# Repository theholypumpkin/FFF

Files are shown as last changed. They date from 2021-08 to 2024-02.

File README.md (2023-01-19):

# NOTE: README ist nicht up to date, Ich werde es irgendwann mal anpassen :D
# Digitales Fridays For Future Demoschild
Dieser Python Skript stellt diverse Bilder sowie live gemessende CO2, Temperatur, Luftfeuchtigkeit sowie Optional Stromverbrauch auf zwei 32x32 LED Matrizen dar.
Der Skript wird auf einem RaspberryPi Pico der Adafruit's Circuit Python 6.3 als Python Interpreter nutzt.

## Anleitung zum selbermachen:
### __Wichtige__ Vorrausetztungen und Vorwissen
- Du musst wissen wie man lötet, oder jemanden kennen der Löten kann
- Erfahrung in der Elektronik (keine Sorge wir arbeiten mit Sehr geringen Spannungen (5V) und Strömen (3A))
- Grundlegende Verständnisse in Programmierung (Sprache Python)

### Material
Das notwendige Material kannst du online bestellen, oder im Laden kaufen, leider gibt es in Deutschland nur wenige Verkäfter mit vernünftigen Preisen. Ich versuche immer einen Weblink zuim kaufen bei mindestens einem Deutschen Händer und einen Händler in der EU oder Großbritannien (GB) an.
Lese bevor du etwas käuftst am besten die gesamte Anleitung einmal durch.

__Wichtig für bestellungen auserhalb des Europäischen Binnenmarkt ist Zoll zu zahlen, der wird oft im Preis nicht angegeben__

*Dem Klima zu liebe verucht bei so weingen Händlern wie möglich zu kaufen dann mussen weniger Parkete verschickt werden, die meisten Produkte findest du bei Reichelt und Pimoroni (GB)*

| Produkt | Händler 1 (DE) | Handler 2 (DE) | Händler 3 |
| --- | --- | --- | --- |
| 1x Raspberry Pi Pico | [Reichelt Elektronik, 3,95 € Online](https://www.reichelt.de/raspberry-pi-pico-rp2040-cortex-m0-microusb-rasp-pi-pico-p295706.html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) | [Conrad Electronic Online, 7,99 €](https://www.conrad.de/de/p/raspberry-pi-mikrocontroller-rp-pico-2348726.html) |  [(GB) Pimoroni, 3,54 €  Online](https://shop.pimoroni.com/products/raspberry-pi-pico) |
| 2x RGB LED Matrizen 32x32 6mm Raster | [Berry Blase; Bereits 32x64 6mm Raster; NUR einmal kaufen 66,90 € Online](https://www.berrybase.de/sensoren-module/led/andere-led-module/64x32-rgb-led-matrix-6mm-raster) | | [(GB) Pimoroni 32x32 6mm Raster 17,70 € Online](https://shop.pimoroni.com/products/rgb-led-matrix-panel) |
| 1x Solar-Charger 1 Ampere (Optional) | [Reichelt Elektronik 9,99 ](https://www.reichelt.de/entwicklerboards-solar-ladegeraet-fuer-6-bis-24-v-panels-debo-pwr-solar2-p266038.html) | [Eckstein Komponente 9,69 € Online](https://eckstein-shop.de/WaveshareSolarPowerManagementModule2Cfor6V-24VSolarPanelEN)
| 2x Solarzellen (Optional) | [Reichelt Elektronik 12,90 € Online](https://www.reichelt.de/entwicklerboards-solarpanel-5-w-debo-solar-5w-p266039.html) | [Amazon 14,99 € Online (Empfehlung)](https://www.amazon.de/gp/product/B08GQ611T2?psc=1) | |
| Solar-Charger 3 Ampere mit __eingebauter Batterie__ (Optional) | | | [(China) Waveshare 25,99$ Online (Empfehlung)](https://www.waveshare.com/product/accessories/power-heat-sinks/solar-power/solar-power-manager-b.htm)|
| 1x Li-Po Batterie (für etwa 45min bis 1h Akkulaufzeit. LED Matrizen haben einen hohen Stromverbrauch) | | | [(GB) Pimoroni 13,27 € Online](https://shop.pimoroni.com/products/high-capacity-lithium-ion-battery-pack) |
| 1x CO2 Sensor CCS881| [Reichelt Elektronik 17,10 € Online](https://www.reichelt.de/entwicklerboards-sensor-fuer-luftqualitaet-ccs811-debo-sens-ccs811-p253655.html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) | | [(GB) Pimoroni 18,29 € Online](https://shop.pimoroni.com/products/adafruit-ccs811-air-quality-sensor-breakout-voc-and-eco2) |
| 1x Temperatursensor DHT22 | [Reichelt Elektronik 6,80 € Online](https://www.reichelt.de/entwicklerboards-temperatur-feuchtigkeitssensor-dht22-debo-dht-22-p224218.html) | [Conrad Electronics Online, 8,49 €](https://www.conrad.de/de/p/joy-it-sen-dht22-temperatur-sensor-1-st-passend-fuer-entwicklungskits-arduino-asus-asus-tinker-board-banana-pi-b-2159178.html) | [(GB) Pimoroni 11,21 € Online](https://shop.pimoroni.com/products/cm2302-dht22-temperature-humidity-sensor-module) |
| Stromsensor INA219 (Optional, wenn du Stromverbrauch messen willst)) | [Reichelt Elektronik 4,15 € Online](https://www.reichelt.de/entwicklerboards-stromsensor-mit-breakoutboard-ina219-debo-sens-power-p266047.html) | | [(GB) Pimoroni 8,85 € Online](https://shop.pimoroni.com/products/ina219-high-side-dc-current-sensor-breakout-26v-3-2a-max-stemma-qt) |
| Diverse Header zum anlöten |[Reichelt 2x 1,35 € Online](https://www.reichelt.de/buchsenleiste-20-polig-vergoldet-2-54-bkl-10120828-p235676.html) & [1x 0,21 € Online](https://www.reichelt.de/40pol-stiftleiste-gerade-rm-2-54-sl-1x40g-2-54-p19506.html) & [1x 2,25 € Online](https://www.reichelt.de/stiftleisten-2-54-mm-1x36-gewinkelt-vergoldet-fis-sl3-25-36g-p292528.html) | | [(GB) Pimoroni (Set mit allem Möglichen Sachen) 6,19 € Online](https://shop.pimoroni.com/products/maker-essentials-various-headers)|
| Divere Kabel zum verbinden | [Reichelt Elektronik 4,80 € Online](https://www.reichelt.de/entwicklerboards-steckbrueckenkabel-25cm-20-kabel-einzeln-debo-kabelset4-p238964.html) | | |
| 1x Hohlstecker zum anschrauben/löten | [Reichelt Elektronik 0,26 € Online](https://www.reichelt.de/hohlstecker-knickschutz-aussen-5-5-mm-innen-2-5-mm-hs-25-14-p8648.html) | [Conrad Electronics, 3,99 €  Online (Einfacher)](https://www.conrad.de/de/p/tru-components-dc-13m-niedervolt-steckverbinder-stecker-gerade-5-5-mm-2-5-mm-1-st-1572162.html) | |
| 1x LED matrix Feather Wing (Optional aber macht das leben einfacher) | [Berry Blase 7,75 € Online](https://www.berrybase.de/dev.-boards/adafruit-feather/featherwing/adafruit-rgb-matrix-featherwing-kit-f-252-r-feather-m0-und-m4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) | [Amazon 14,06 € Online](https://www.amazon.de/Adafruit-RGB-Matrix-Featherwing-Kit/dp/B07GYYB795) | [(GB) Pimoroni 7,08 € Online](https://shop.pimoroni.com/products/adafruit-rgb-matrix-featherwing-kit-for-m0-and-m4-feathers)
| Stemma QT Kabel (optinal wenn du weniger löten willst) Nur möglich wenn du auch den CO2 Sensor und den Stromsensoren bei Pimoroni/Adafruit/Sparkfun kauft| | | [(GB) Pimoroni 1,47 € Online](https://shop.pimoroni.com/products/jst-sh-cable-qwiic-stemma-qt-compatible?variant=31910609846355) & 2x dieses Kalbel (nur wenn du Stromsensor hast)[(GB) Pimoroni 1,47 € Online](https://shop.pimoroni.com/products/jst-sh-cable-qwiic-stemma-qt-compatible?variant=31910609813587)|
| 2x Alte USB Handy-Ladekabel, eins davon wird zerschnitten| | | |
| Wekzeuge wie Schraubenzieher Schraubenschüssen, Sägen, Akkubohrer, Sandpapier, etc. | | | |
| Steckplatine (optional, macht aber das löten um einiges einfacher)| | | |
| Eine Holzkonstruktion, und  dazu passende Schrauben. Hier lass ich dir freie Auswahl wie du diese Gestalten willst. | | | |

So jetzt wo alles hast können wir anfangen.

## Schritt 1 Löten
Wir fangen mit dem Löten der einzelen Komponenten an:
#### 1.
* Wenn deine Stromsensoren (INA219) und CO2 sensor (CCS881) von Pimoroni,Adafruit oder Sparkfun und die Optionale Stemma QT/Qwiic Kabel gekauft hast dann kannst du dir etwas löten ersparen, und einfach nur 2 Sensoren in eine Reihe Stecken, Diese Sensoren haben auf den beiden kuzen Seite einen Steckverbinder wo man ein Solches Kabel einstecken kann. Wenn du von Anderen Herstellen gekauft hast, dann musst du die (meistens Beigelegte) Stiftleiste anlöten. [Hier gibt es eine Anleitung mit Bildern, wie du das bei dem CO2 Sensor macht, das selbe gilt auch für den Stromsensor](https://learn.adafruit.com/adafruit-ccs811-air-quality-sensor/assembly).
#### 2.
* Je nachdem wo du deinen Temperatur und Luftfeuchtigkeitssensor gekauft hast, musst du löten oder auch nicht. bei dem von Pimoroni musst du nicht löten, braucht keine Platine zum anlöten oder Wiederstände, der Kommt komplett vorbereitet, du muss dann nur die Kabel anschließen.[Wenn du einen der anderen hast, dann kannst du hier naschauen wie du ihn anschließt](https://learn.adafruit.com/dht/connecting-to-a-dhtxx-sensor). Achte auf den Wiederstand von _20-50 Kilo Ohm_.
Damit sind alle Snesoren vorbereitet.
#### 3.
* Nun müssen wir die Buchsenleistenleisten an den Raspberry Pi Pico anlöten. Eine Buchenleiste sieht wie im Bild hier aus: Bild 1 Buchsenleiste
* Der Raspbbery Pi Pico hat 40 Sogenannte Pins oben. Davon habe 28 spezielle Funktionen. Interessiert uns aber alles nicht. Um uns das leben einfacher zu machen, schauen wir uns das Pinout Diagram an was der Hersteller bereit stellt. Bild 2 Raspberry Pi Pico Pinout Pinout Diagram. Hier ist sehr viel zu sehen, aber vieles ist für dich egal, wenn du den Quellcode nicht verändern willst.
* Wir Orientiern nun unseren Raspberry Pi Pico genauso wie im Bild, das Logo mit der Himbeere kommt nach unten und die USB Buchse kommt nach oben.
* Nun suchen wir aus unsern Set an Buchenleisten So viele raus, das wir insgesamt 12 Buchen haben. Wenn du das Set von Pimoroni gekauft hast, dann musst du die Kurzen Enden der buchen mit Sandpapier etwas abreiben, damit sie nebeneinander passen. Wenn du von Reichelt gekauft hast, kannst du dir einfach 14 von den 20 Buchen abschneiden. Du braucht 2 mal Leisten der Länge 12 und 2 mal gewinkelte Stiftleisen der Länge 6.
* * Diese Leisten löten wir jetzt auf beide Seiten an, so das sie nach oben Zeigen. Das heißt wir wollen die Leisten und die Himbeere zugleich sehen können. Wir löten sie aber nicht irgendwo an.
* * Vergleiche das Diagram und seine Beschriftungen Die Leisten werden von Pin 7 (GP5) bis Pin 18 (GND) angelötet, die oberen 6 Pins neben der USB-Buche bleiben frei. Um zu wissen wo diese Pins sind, könne wir uns wieder das Pinout Diagram anschauen. Jeder der Pins zwischen Pin 7 und 18 muss angelötet werden.
* * * auf der anderen Seite machen wir das selbe. Wir lassen wieder die Oben 6 Pins frei. Löten die Buchenleiste an alle Pins zwischen Pin 34 (GP38) und Pin 23 (GND) an.
* * * Ihr könnt nochmal Prüfen auf beiden Seiten  des USB Stecker 6 "Löcher"  frei sind und auf Beiden Seiten unten bei der Himbeere jeweils 2 "Löcher" sind.
* *  * Nun kommen wir zu den 6 oben Freigelassen Pins auf beiden Seiten. diese füllen wir mit den Gewinkelten Stiftleisten auf. Also die die um die Ecke gehen. Bild 3 Gewinkelte Buchsenleiste du kannst einfach 6 abscheiden von denen die du gekauft hast.
Damit ist der Raspberry Pi Pico fertig gelötet, lege ihn ersteinmal beiseite, ihn brauchen wir erst einmal nicht.
#### 4.
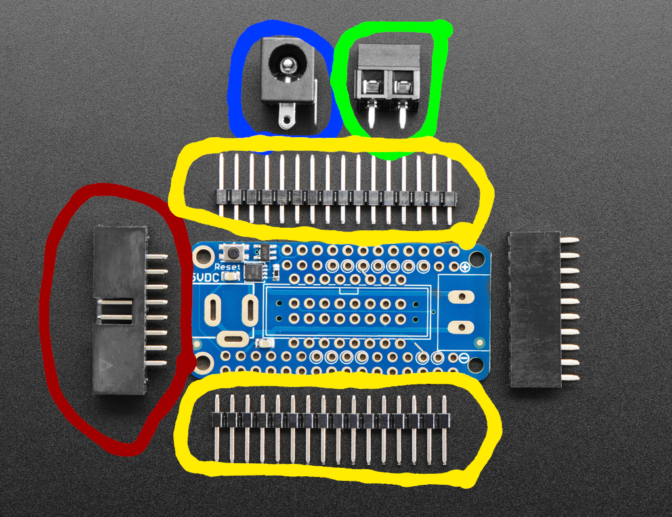
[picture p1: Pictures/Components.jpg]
Bild 1 Featherwing Bild 5 Komponenten
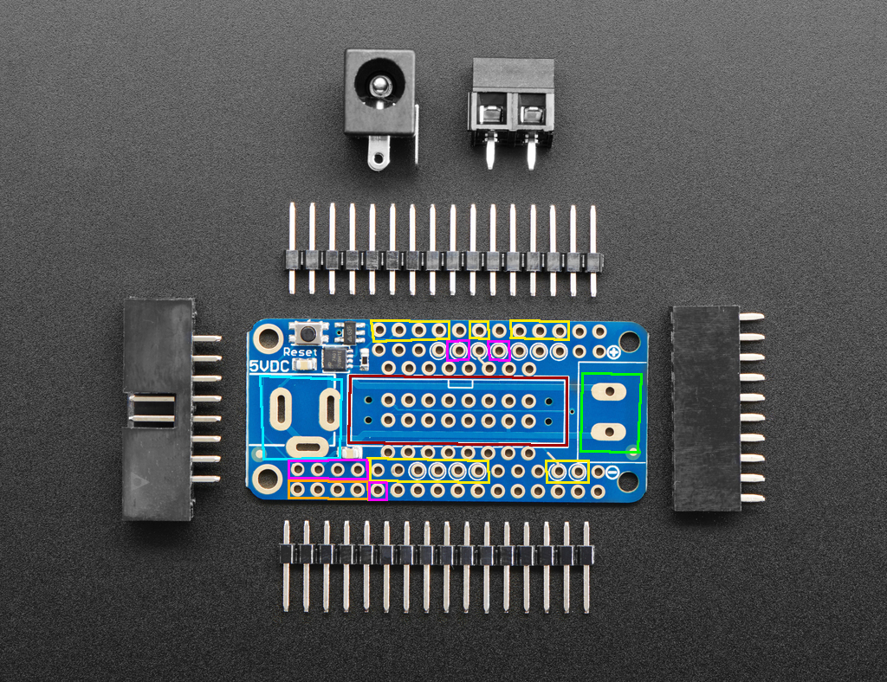
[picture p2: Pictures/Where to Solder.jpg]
Bild 6 Featherwing Bild 2 Wo hin löten
* Nun Kommen wir zum Löten, des "Featherwings", der ist realtiv komplizert zu löten, wenn du Probleme damit hast, dann frage einen Verwanten oder einen Freund. Im Set ist sehr viel Zeug, wir brauchen, da haben den Hohlsteckerbuchse (im Bild 5 Blau), den IDC Buchse auch Schneidklemme genannt (im Bild 5 Rot), eine Schraubklemme (im Bild 5 Grün), und ein paar Stiftleisten (im Bild 5 Gelb).  
* Wir fangen mit der IDC Buchse/Schneidklemme Bild 5 (Rot) an. Die ist ja im Bild 6 (Rot) makiert und hat auf einer Seite eine Kerbe. __Die Kerbe ich ganz wichtig!__ Die IDC Buchse/Schneidklemme gehört auf dem Featherwing in die Mitte (auch Rot markiert). __Achte auf die Kerbe, die auch auf dem Featherwing Markiert ist. Die Kerbe auf der IDC Buchse muss auf der Selben Seite sein, wie die des Featherwing__
* Jetzt kommen wir erst einmal zum Schwersten Teil, die Stiftleisten.
* * an alle im Bild 6 (__GELB__) Markierten Flächen, und auch __nur__ an diesen positionen Brauchen gerade Stiftleisten nach Unten. Wenn du dir nicht sicher bist, was die Geraden Stiftleisten sind, hier ist noch einmal ein Bild Bild 7 Gerade Stiftleiste. Mit Stiftleisten nach unten ist gemeint, dass wenn wir den "Featherwing" genauso wie in Bild 5 vor uns haben, dann können wir die Stifte nicht sehen. __Aufpassen, die Stifte sind versetzt. Einmal sind sie auf der äußerne Reihe und einmal auf der mittleren Reihe__
* * An den Magenta/Lila sind Auch Stifte anzubringen, aber diese mal Müssen sie nach __Oben__ Zeigen! Das heißt wenn wir wollen die Stift sehen, wenn wir den "Featherwing" genauso wie im Bild 6 Betrachten.
* * Nun kommen noch an die Orange makierten Stellen gewinkelte Stifte wie im letzten Unterpunkt von Punkt 3.
* Als nächstes installieren wir die Schraubklemme Bild 5 (Grün) auf der Rechten Seite Bild 6 (Grün). Stelle sicher, das die Schrauböffnung nach Außen zeigt.
* Installiere die Hohlsteckerbuchse Bild 5 (Dunkelblau) an die Stelle in Bild 6 (Hellblau), hier kannst du eigentlich nichts flasch machen es geht nur in ein einzige weise anzulöten.
Nun haben wir alles angelötet fast ferig mit dem allem was Gelötet werden muss aber das Kommt später noch einmal.
## Schritt 2 Vorbereiten und Programmieren den Reaspberry Pi Pico
#### 1.
* Wir gehen in Internet und [laden uns Circuit-Python 6.3.0 herunter](https://circuitpython.org/board/raspberry_pi_pico/). Wen zu deinem Zeitpunkt bereits eine neuere Version verfügbar ist, dann musst du trotzdem die Version 6.3.0 installieren, die "alte" Verion die du brauchts findest du [hier](https://adafruit-circuit-python.s3.amazonaws.com/bin/raspberry_pi_pico/de_DE/adafruit-circuitpython-raspberry_pi_pico-de_DE-6.3.0.uf2 "Direct Download") Nun müssen wir die Datei auf den Rasperry Pi Pico kopieren. Dafür musst du den Knop der auf dem Pico ist gedrückt halten, und dann ihn mit dem Handy-Lade-Kabel an dne Computer anschließen. In deinem Datei-Explorer auf dein Computer Müsste nun eine "USB-Stick" names __`RPI-RP2`__ auftauchen. Nun ziehst du einfach die Datei die du heruntergelanden hast, in diesen Ordner. Der __`RPI-RP2` "USB-Stick" sollte verschwinden__, und kurz darauf ein neuer "USB-Stick" names __`CIRCUITPY`__ auftauchen. Das wars. Lasse den Raspberry Pi Pico eingesteckt in deinem Computer. *Falls du probleme hattest, hier ist noch einmal eine [Anleitung online](https://learn.adafruit.com/getting-started-with-raspberry-pi-pico-circuitpython/circuitpython)*
#### 2.
* Nun gehst du auf dieser Website wo du gerade das ließt, ganz nach oben, und dort ist ein Grüner Knopf, der sagt __Code__ wenn du darauf klickst, dann bekommst du ein kleines Fester. Hier gibt es einen weitern Knopf Names __Download Zip__ diesen klickst du an und der Quellcode für das Demoschild wird Heruntergeladen. Wenn du zu faul bist, bis nach ganz oben zu zu Scrollen [hier kannst du den Code auch herunterladen](https://github.com/theholypumpkin/FFF/archive/refs/heads/main.zip)
#### 3.
* die Heruntergeladen Datei musst du nun entpacken mit einem Program wie WinRar oder 7zip, ich gehe aber davon aus das du so etwas bereits installiert hast.
#### 4.
* Im entpackten Ordner gibt es 3 sachen die du auf den __`CIRCUITPY`__ "USB-Stick" kopieren musst.
* * Du musst den Ordner names `lib` auf den __`CIRCUITPY`__ "USB-Stick" kopieren
* * Du musst die Dateien `bitmap.bmp` und `code.py` "USB-Stick" kopieren. *Gegebennefalls heißen die dateien auch nur `bitmap` `code`*
Jetzt hast du schon alles Programmiert was du machen musst, wenn wir nachher dann alles verkabeln, dann sollte deine LED Matrizen die Diashow anzeigen.
## Schritt 3 Alles verkabeln und noch etwas mehr löten
* placholder

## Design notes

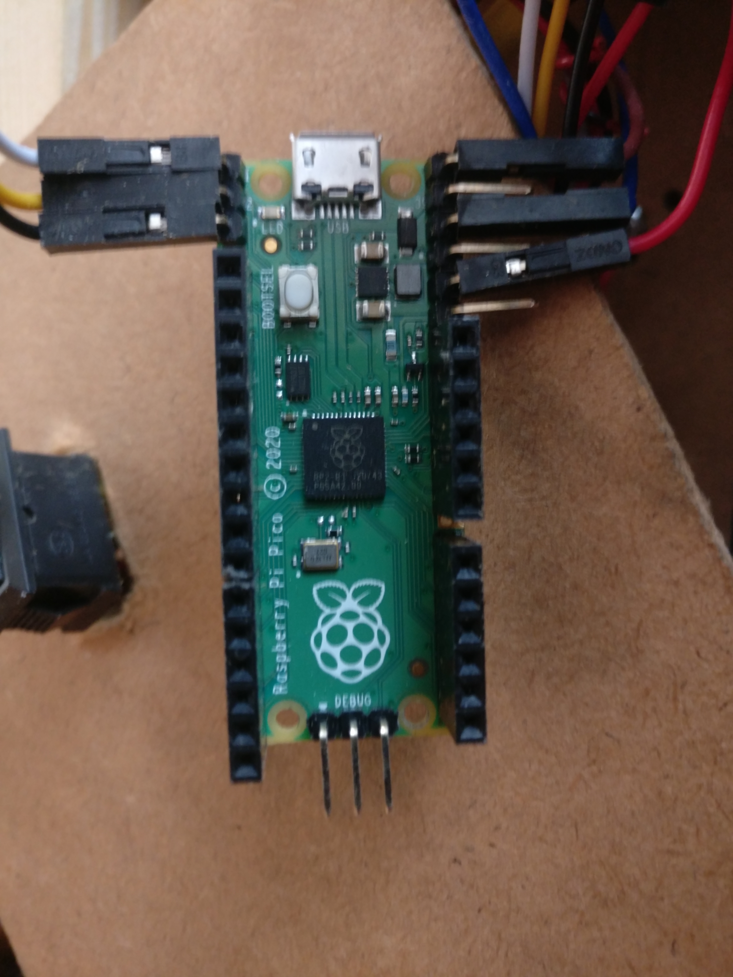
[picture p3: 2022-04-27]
Pictures/Pos_Buchsenleisten.jpg

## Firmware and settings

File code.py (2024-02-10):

import board

from math import floor

from switch import Switch  # one switch case implermetation

import time  # to make the controller sleep
import busio  # i2c spi uart etc.

import displayio  # lib to disoplay more complex things on the martrix
import rgbmatrix  # lib for the matrix
import terminalio
import framebufferio
from adafruit_display_text.label import Label
import adafruit_ccs811
import adafruit_dht
import adafruit_ina219  # Ampere / Volt Sensor
import multichannel_gas_sensor

i2c = busio.I2C(board.GP13, board.GP12)
ccs = adafruit_ccs811.CCS811(i2c)
dht = adafruit_dht.DHT22(board.GP11)
ina_battery = adafruit_ina219.INA219(i2c)
nox_co = multichannel_gas_sensor.MultichannelGas(i2c)

switch = Switch()

# Global Variables
image_cycle = 0
i = 0 # TODO set value to 0
# solar_power = []
power_usage = []
co2_concentration = []
co_concentration = []
nox_concentration = []
temperature = []
humidity = []
# -----------------------------------------------------------------------------
# RGB Pins: [GP17 = R1, GP16 = G1, GP18 = B1, GP20 = R2, GP19 = G2, GP21 = B2]
# ADDR Pins: [GP22 = A, GP26 = B, GP27 = C, GP28 = D]
# GP10 = CLK
# GP15 = Latch
# GP14 = OE (output enable)
# -----------------------------------------------------------------------------
# Matrix Setup
displayio.release_displays()

matrix = rgbmatrix.RGBMatrix(  # Gives me 2^4 = 16 Brightness levels to save
                               # power we make it dimer
    width=64,
    height=32,
    bit_depth=6,
    rgb_pins=[board.GP17, board.GP16, board.GP18,
              board.GP20, board.GP19, board.GP21],
    addr_pins=[board.GP22, board.GP26, board.GP27, board.GP28],
    clock_pin=board.GP10, latch_pin=board.GP14, output_enable_pin=board.GP15,
    doublebuffer=True)

display = framebufferio.FramebufferDisplay(matrix, auto_refresh=True)
# -----------------------------------------------------------------------------
# Create 3 Text Columns
line1 = Label(terminalio.FONT,
              color=0x000000,
              text="")
line1.x = 63
line1.y = 31

line2 = Label(terminalio.FONT,
              color=0x000000,
              text="")
line2.x = 63
line2.y = 31

line3 = Label(terminalio.FONT,
              color=0x000000,
              text="")
line3.x = 63
line3.y = 31
# -----------------------------------------------------------------------------
# Loading Bitmaps to display imanges
bitmap_file = open("bitmap.bmp", "rb")
bitmap_bmp = displayio.OnDiskBitmap(bitmap_file)

bitmap_tiles = displayio.TileGrid(bitmap_bmp,
                                  pixel_shader=getattr(bitmap_bmp,
                                                       'pixel_shader',
                                                       displayio.
                                                       ColorConverter()),
                                  width=1, height=1, tile_height=32,
                                  tile_width=64, default_tile=0, x=0, y=0)

bitmap_group = displayio.Group()
bitmap_group.append(bitmap_tiles)
bitmap_group.append(line1)
bitmap_group.append(line2)
bitmap_group.append(line3)
display.show(bitmap_group)
# -----------------------------------------------------------------------------
# Scroll a line in a defined direction or multiple directions


def scroll(line, x, y=0, iterations=1):
    for i in range(iterations):

        line.x = floor(line.x + x)
        line.y = floor(line.y + y)
        line_width = line.bounding_box[2]
        line_height = line.bounding_box[3]

        if line.x < -line_width:
            line.x = display.width

        elif line.x >= display.width:
            line.x = -line_width

        if line.y < -line_height:
            line.y = display.height

        elif line.y >= display.height:
            line.y = -line_height

        time.sleep(0.06250)  # Wait before restarting the loop
# -----------------------------------------------------------------------------


def read_sensors():
    # TODO Try-Catch-block!
    power_usage.append(ina_battery.power)  # Read the power usage every tile
    # print(f"{ina_battery.power}W")
    # solar_power.append(ina_solar.power)  # Read power production on every til
    try:
        co2_concentration.append(ccs.eco2)
    except RuntimeError as e:
        #print("Execption: ", e.args)
        pass
        #co2_concentration.append(450)
    # else:
        # print("co2 concentration appended to list")

    nox_concentration.append(nox_co.measure_NO2)
    co_concentration.append(nox_co.measure_CO)
    # print("co and nox concentration appended to respective lists")
    try:
        temperature.append(dht.temperature)
        humidity.append(dht.humidity)
    except RuntimeError as e:
        pass
        #print("Execption: ", e.args)  # When the checksum did not validated
        #temperature.append(20)  # TODO adjust to tomorrows avg temperature
        #humidity.append(85)  # TODO adjust to tomorrows avg humidity
    # else:
      #  print("temperature and humidity appended to list")
# -----------------------------------------------------------------------------
# Set text, when tile zero and one are displayed


def tile_line_values(line, text="", color=0x000000,
                     background_color=None, x=63, y=31):
    line.text = text
    line.color = color
    line.background_color = background_color
    line.x = x
    line.y = y
# -----------------------------------------------------------------------------
# The tile Show your Stripes


def tile_0():
    read_sensors()
    tile_line_values(line1)  # Reset line1
    tile_line_values(line2, "#ShowYourStripes", 0xff0000, x=63, y=24)
    scroll(line2, x=-1, iterations=158)
# -----------------------------------------------------------------------------
# The tile displaying the Sun and Battery


def tile_1():
    # We display the mean (avarage) of all power_usage readings of last 2 min
    read_sensors()
    # print(power_usage)
    tile_line_values(line2, "{:.2} W".format(sum(power_usage)/len(power_usage)),
                     0xffffff, 0x000000, x=20, y=16)
    power_usage.clear()  # Remove all values from array so we can fill it again
# -----------------------------------------------------------------------------
# The tile displaying the Green Gost


def tile_2():
    read_sensors()
    tile_line_values(line1, "Buhh!", 0x16ca31, x=32, y=5)
    tile_line_values(line2, "Bring", 0x16ca31, x=32, y=15)
    tile_line_values(line3, "Oko!", 0x16ca31, x=32, y=25)
# -----------------------------------------------------------------------------
# The tile displaying the Smokestacks and Carbon Monoxide Levels


def tile_3():
    read_sensors()
    # print(co_concentration)
    tile_line_values(line2)  # Reset Lines
    tile_line_values(line3)
    # We display the avarage CO2 concentration of the last two minutes
    try:
        tile_line_values(line1,
                         f'CO {int(sum(co_concentration)/len(co_concentration))}',
                         0xff0000, x=16, y=8)
    except ZeroDivisionError:
        print("ZeroDivisionError")
    #tile_line_values(line1, "CO: 150", 0xff0000, x=20, y=10)
    tile_line_values(line2, "ppb", 0xff0000, x=40, y=20)
    co_concentration.clear()
# -----------------------------------------------------------------------------
# Red for the trafic light


def tile_4():
    read_sensors()
    tile_line_values(line1, "Ampel;", 0x00ff00, x=16, y=8)
    tile_line_values(line2, "das Klima", 0xffff00, x=16, y=16)
    tile_line_values(line3, "ist Rot!", 0xff0000, x=16, y=24)
    time.sleep(10)
    # TODO Scrolling or have two lines which are displayed after oneother
# -----------------------------------------------------------------------------
# The Temperature tile


def tile_5():
    read_sensors()
    # print(temperature)
    # Print the temperature with on foating point number
    tile_line_values(line1, "{:.2} C".format(sum(temperature)/len(temperature)),
                     0xffff00, x=12, y=6)

    tile_line_values(line2, f'{int(sum(humidity)/len(humidity))}%',
                     0x0000ff, x=26, y=24)
    temperature.clear()
    humidity.clear()
# -----------------------------------------------------------------------------
# The RWE is Poop tile has no text


def tile_6():
    read_sensors()
# -----------------------------------------------------------------------------
# Shows CO2 concentration


def tile_7():
    read_sensors()
    # print(co2_concentration)
    tile_line_values(line2)  # Reset Lines
    tile_line_values(line3)
    # We display the avarage CO2 concentration of the last two minutes
    tile_line_values(line2,
                     f'{int(sum(co2_concentration)/len(co2_concentration))} ppm',
                     0xff0000, x=2, y=25)
    tile_line_values(line1, "CO2:", 0xff0000, x=2, y=16)
    co2_concentration.clear()
# -----------------------------------------------------------------------------
# Nuclearpower no, thnak you!


def tile_8():
    read_sensors()
    tile_line_values(line1, "Atomkraft Nein Danke!", 0xffffff, x=4, y=4)
    scroll(line1, x=-1, iterations=127)
# -----------------------------------------------------------------------------
# The tile displaying the Nitrogendioxide concentration


def tile_9():
    read_sensors()
    try:
        tile_line_values(line1, f'{int(sum(nox_concentration)/len(nox_concentration))}',
                         0xffffff, x=32, y=12)
    except ZeroDivisionError:
        print("ZeroDivisionError")
    nox_concentration.clear()
# -----------------------------------------------------------------------------


def tile_10():
    read_sensors()
    tile_line_values(line1, "Luetzi", 0xffff00, x=20, y=12)
    tile_line_values(line2, "BLEIBT!", 0xffff00, x=24, y=24)
# -----------------------------------------------------------------------------
# Fescher Bleibt


def tile_11():
    read_sensors()
    # Print the temperature with on foating point number
    tile_line_values(line1, "Fecher bleibt!, RiWaTu stoppen!",
                     0xffffff, x=4, y=4)
    scroll(line1, x=-1, iterations=187)
# -----------------------------------------------------------------------------
# Add an case for each tile
case_tile_0 = tile_0
case_tile_1 = tile_1
case_tile_2 = tile_2
case_tile_3 = tile_3
case_tile_4 = tile_4
case_tile_5 = tile_5
case_tile_6 = tile_6
case_tile_7 = tile_7
case_tile_8 = tile_8
case_tile_9 = tile_9
case_tile_10 = tile_10
case_tile_11 = tile_11

# adding cases to switch
switch.add_case(0, case_tile_0, True)
switch.add_case(1, case_tile_1, True)
switch.add_case(2, case_tile_2, True)
switch.add_case(3, case_tile_3, True)
switch.add_case(4, case_tile_4, True)
switch.add_case(5, case_tile_5, True)
switch.add_case(6, case_tile_6, True)
switch.add_case(7, case_tile_7, True)
switch.add_case(8, case_tile_8, True)
switch.add_case(9, case_tile_9, True)
switch.add_case(10, case_tile_10, True)
switch.add_case(11, case_tile_11, True)

# -----------------------------------------------------------------------------
# Wait for the sensor to be ready
while not ccs.data_ready:
    pass
# The main program loop
while True:
    if (image_cycle + 0.1) < time.monotonic():
        bitmap_tiles[0] = i
        sub = time.monotonic()  # get the time before the execution of switch
        switch.case(i)
        i += 1
        # substract the execution time of switch from the sleep time
        dif = time.monotonic() - sub
        # print(f'dif before: {dif}')
        if dif > 5:  # When a tile takes longer than 5 sec to process
            dif = 0
        else:
            dif = 5 - dif  # when tile takes less than 5 sec to process
        # print(f'difafter:{dif}')

        image_cycle = time.monotonic()
        if (i > 11):
            i = 0
    time.sleep(dif)
    tile_line_values(line1)  # Reset the line Label
    tile_line_values(line2)
    tile_line_values(line3)

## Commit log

2021-08-06 Final commit: Added acidantially removed line
    Added line which got removed by accident which completely broke the cycling though tiles.
    [code.py]
2022-04-27 Reintroduced ReadMe. New Instruction/BOM soon
2022-09-23 Update to CP7, new PCB, Pin Change, new bitmap
2024-03-08 added fritzing scematic
    [FFF.fzz]
